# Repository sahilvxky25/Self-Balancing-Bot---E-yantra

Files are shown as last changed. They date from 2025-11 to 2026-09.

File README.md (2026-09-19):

# Self Balncing Bot - E-yantra

## 2025-26

## Project Overview
This repository contains the hardware design assets, control firmware, and task-wise implementation files for the e-Yantra self-balancing bot project by Team IN KrishiBalancer.

The robot is a two-wheeled self-balancing platform with differential drive, IMU-based attitude estimation, encoder feedback, and PID-based control for balance and motion.

## System Details
### Control Approach
- Inner loop: angle stabilization PID for upright balance
- Outer loop: velocity PID for movement regulation
- Yaw control support for turning and heading correction

### Core Hardware/Modules Used
- MPU6050 IMU (tilt and angular-rate sensing)
- Dual DC motors with driver-based PWM control
- Wheel encoders for velocity feedback
- Servo interfaces (used in task-specific implementations)
- Bluetooth serial interface in task variants

### Repository Content Includes
- Arduino firmware files for multiple tasks (`*.ino`)
- Python simulation/control scripts for task solutions (`task*_solution.py`, `Task*.py`)
- Mechanical CAD/export files (`*.stl`, `*.f3d`)
- Reference PDFs for arena/obstacles and rotation matrix

### Participants
- Sahil Patra
- Somya Ranjan Suar
- Aiyush Anand
- H Noah Siddhant

### Team
- IN KrishiBalancer
- From NIT Rourkela

## Links
- https://youtu.be/N_6_f0RvH_E - Task 4B
- https://youtu.be/0fvfJjwpf_w - Task 5B
- https://youtu.be/oQIns9DvQoQ - Task 6
- https://youtu.be/U5AuzeMZjNM - Task 6- Bonus Configuration

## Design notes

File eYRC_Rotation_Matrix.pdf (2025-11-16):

November 13, 2025

## 1 Introduction

2D Rotation Matrix and Vector Rotation

A rotation in two-dimensional space by an angle θ (measured counterclockwise) about the origin can be represented using the rotation matrix:

R(θ) =
cos θ − sin θ
sin θ cos θ

Let the original vector be

v =

x
y

When this vector is rotated by an angle θ, the new vector v

′
is obtained by
multiplying the rotation matrix with the original vector:

v

′ = R(θ)v =

cos θ − sin θ
sin θ cos θ

x
y
=
x cos θ − y sin θ
x sin θ + y cos θ

Hence, the rotated vector v

′ has coordinates

(x

′

, y′
) = (x cos θ − y sin θ, x sin θ + y cos θ).

Transforming Position Error from Global Frame to Robot Frame

Let the position error in the global (world) frame be represented as

eg =

dx

dy
,

and let the robot’s orientation (heading) be given by the angle θ = yaw, measured counterclockwise.
To express this error vector in the robot’s local coordinate frame, we must rotate it by an angle −θ (i.e., the inverse of the robot’s heading). This transformation is given by the rotation matrix:

R(−θ) =
cos θ sin θ
− sin θ cos θ

1

Hence, the error vector in the robot’s frame is:

er = R(−θ)eg =

cos θ sin θ
− sin θ cos θ

dx

dy
=
cos θ dx + sin θ dy

− sin θ dx + cos θ dy

The components of er are therefore:
(
x

′ = cos θ dx + sin θ dy, (lateral error)

y

′ = − sin θ dx + cos θ dy, (forward error)

Thus, the forward position error (along the robot’s local y-axis) is:

position error = cos θ dy − sin θ dx

(*Note- You need to use x and y component of setpoint to calculate dx and dy)

2

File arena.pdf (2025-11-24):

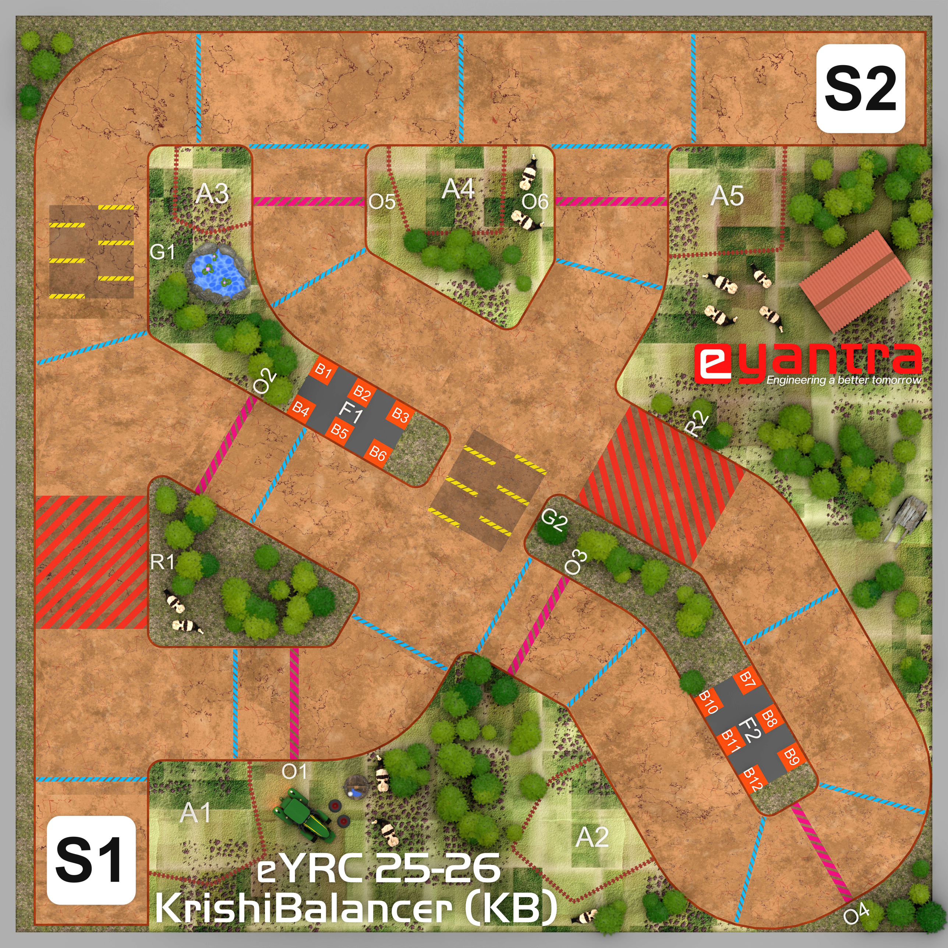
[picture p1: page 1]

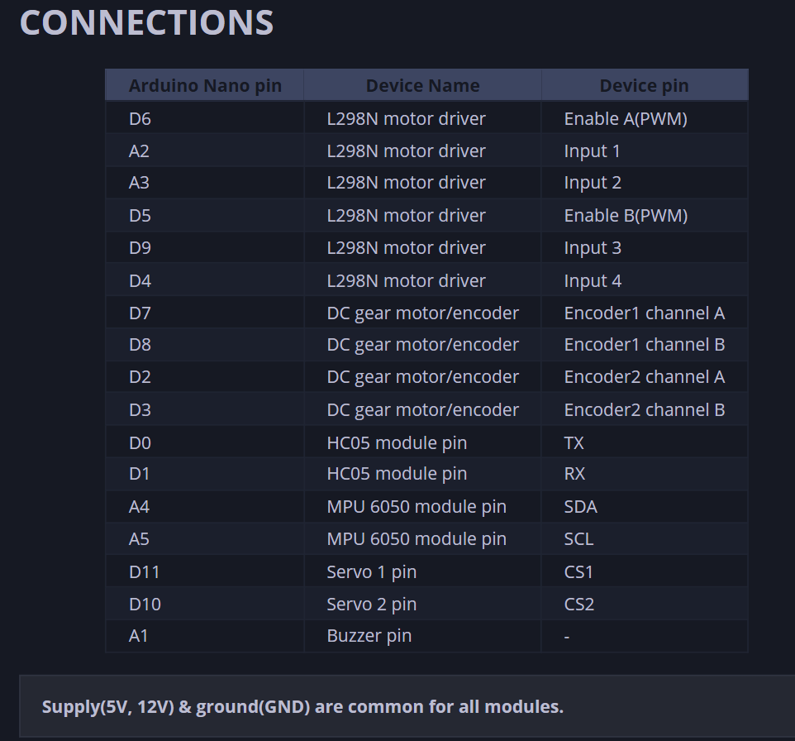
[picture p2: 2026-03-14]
{E6FBB188-6DD0-4D14-BB2B-AFEDF53BD891}.png

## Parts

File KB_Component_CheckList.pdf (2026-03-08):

## eYRC 2024-25 Krishi_Balance (KB) Theme Component Checklist

Sr. No. | Component Name | Image | Qty | Verified by Theme Develop er | Verified by Team | Product Details / DataSheet / Manual
1 | Arduino Nano | | 1 | | | specification (https://robu.in/product/arduino-nano-board-r3-with-ch340-chip-wo-usb-cable-solderedarduino-nano-r3-wo-usb-cable-soldered/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)
| USB-B type Mini cable (Arduino nano cable) | | 1 | | | –
| N20 Motors | | 2 | | | specification (https://robu.in/product/n20-12v-300rpm-micro-metal-gear-motor-with-encoder/)
| N20 Wheels | | 2 | | | specification (https://robu.in/product/3pi-miniq-car-wheel-tyre-42mm-n20-dc-gear-motor-wheel/)
| N20 Clamp, bolts, and nuts | | 2 clamps, 4 bolts, 4 nuts | | | –
| N20 Motor connectors | | 2 | | | –
3 | MPU6050 | | 1 | | | link (https://robu.in/product/mpu-6050-gyro-sensor-2-accelerometer/?gad_source=1)
| Bluetooth Module | | 1 | | | manual (https://components101.com/sites/default/files/component_datasheet/HC-05%20Datasheet.pdf)
| Voltage Checker | | 1 | | | –

2

Sr. No. | Component Name | Image | Qty | Verified by Theme Develop er | Verified by Team | Product Details / DataSheet / Manual
| Jumper caps | | 6 | | | –
| MG90S Servo Motor | | 2 | | | specification (https://robu.in/product/towerpro-mg90s-mini-digital-servo-motor-180-rotation-standard-quality/?gad_source=4)
| Toggle switch | | 1 | | | specification (https://robu.in/product/mini-mts-203-6-pin-dpdt-6a-125vac-toggle-switch-pack-of-5/)
5 | Li-po Battery 3S 1000mAh | | 1 | | | specification (https://robokits.co.in/batteries-chargers/skycell-li-ion-battery/7.4v-li-ion-batteries-6.4-8.4v/lithium-ion-rechargeable-battery-pack-7.4v-2000mah-2c)

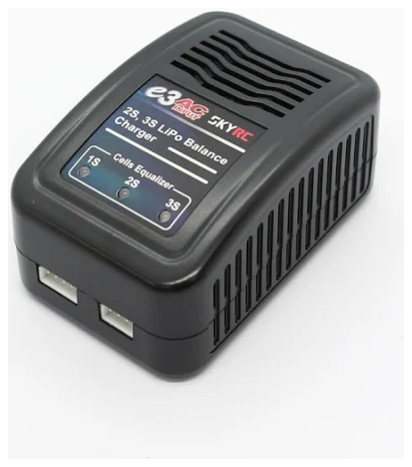
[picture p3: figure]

6 | Battery Adaptor | | 1 | | | –

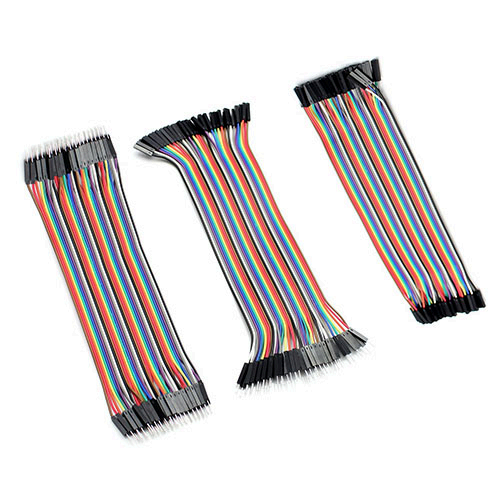
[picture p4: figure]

7 | Jumper Wires (M/M, M/F, F/F) | | 20 each | | | --
8 | Bolts (3mm) and Nuts (3mm) | | 16 Bolts, 8 nuts | | | --
| Spacers 6cm (F/F) | | 6 | | | –
9 | PCB | | 1 | | | --

4

Sr. No. | Component Name | Image | Qty | Verified by Theme Develop er | Verified by Team | Product Details / DataSheet / Manual
| XL4015 Buck converter | | 1
10 | Foam Cubes (5x5x5 cubic cm) | | 7 | | | —

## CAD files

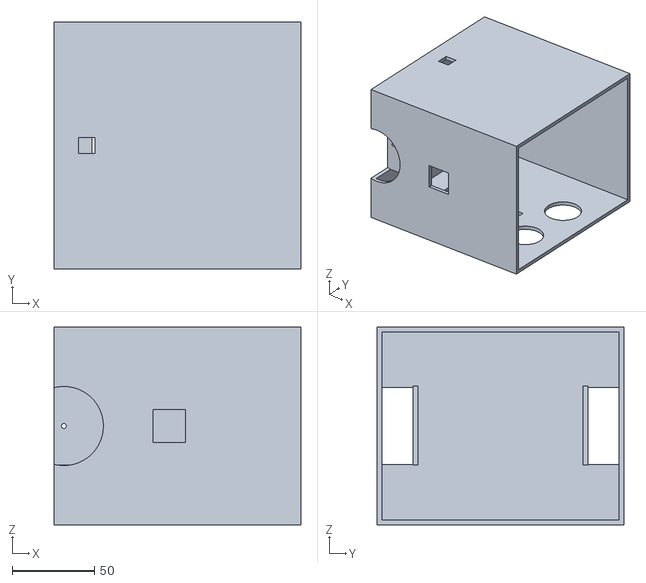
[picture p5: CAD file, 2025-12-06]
MAIN CHASSIS.stl
150.0 x 150.0 x 120.0

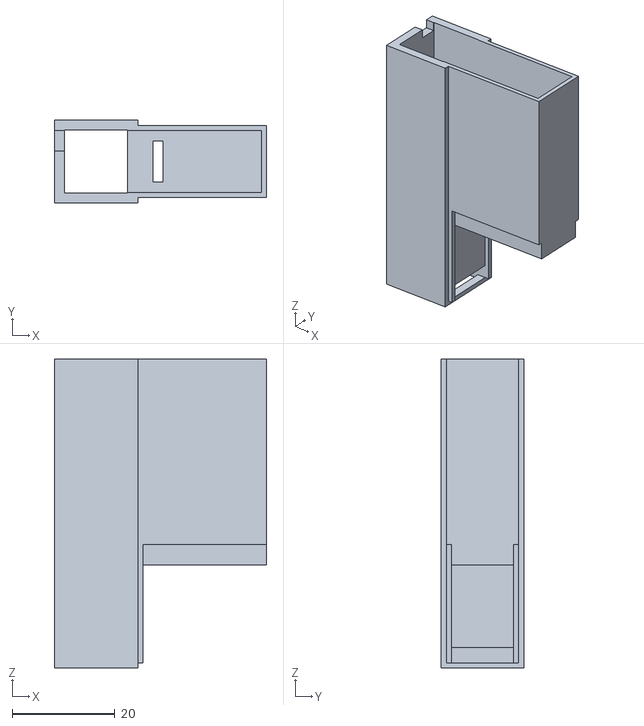
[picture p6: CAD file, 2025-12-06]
main_arm.stl
41.2 x 16.2 x 60.0

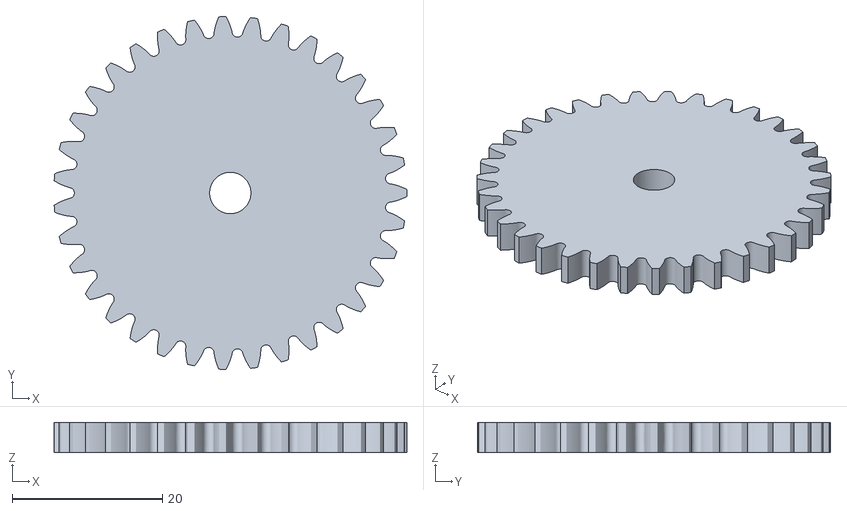
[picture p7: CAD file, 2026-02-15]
Spur Gear (35 teeth).stl
46.9 x 47.0 x 4.00

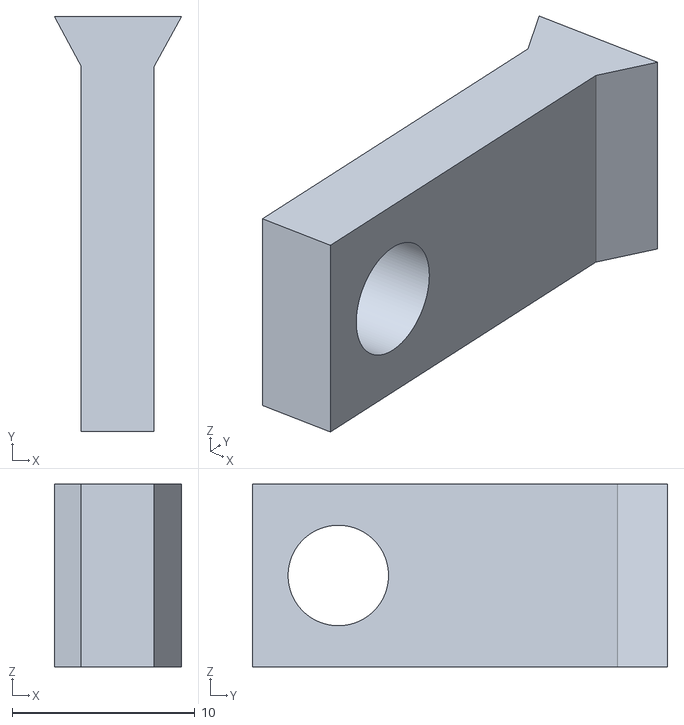
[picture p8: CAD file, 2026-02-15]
Mounter.stl
6.97 x 22.7 x 10.0

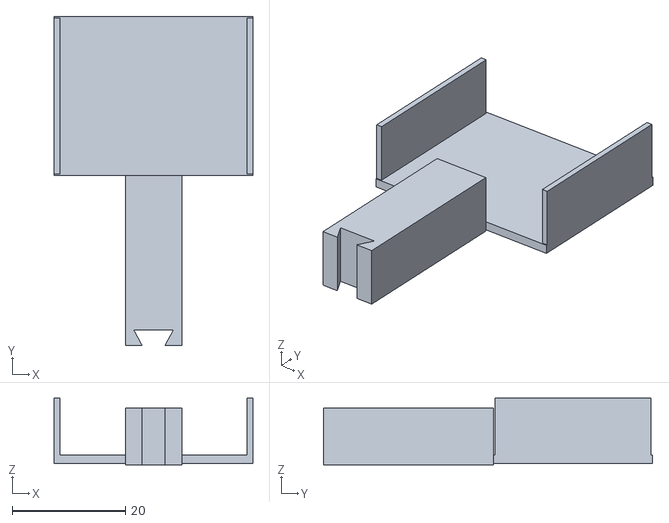
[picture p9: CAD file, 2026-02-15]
servo_rack.stl
35.0 x 58.0 x 11.8

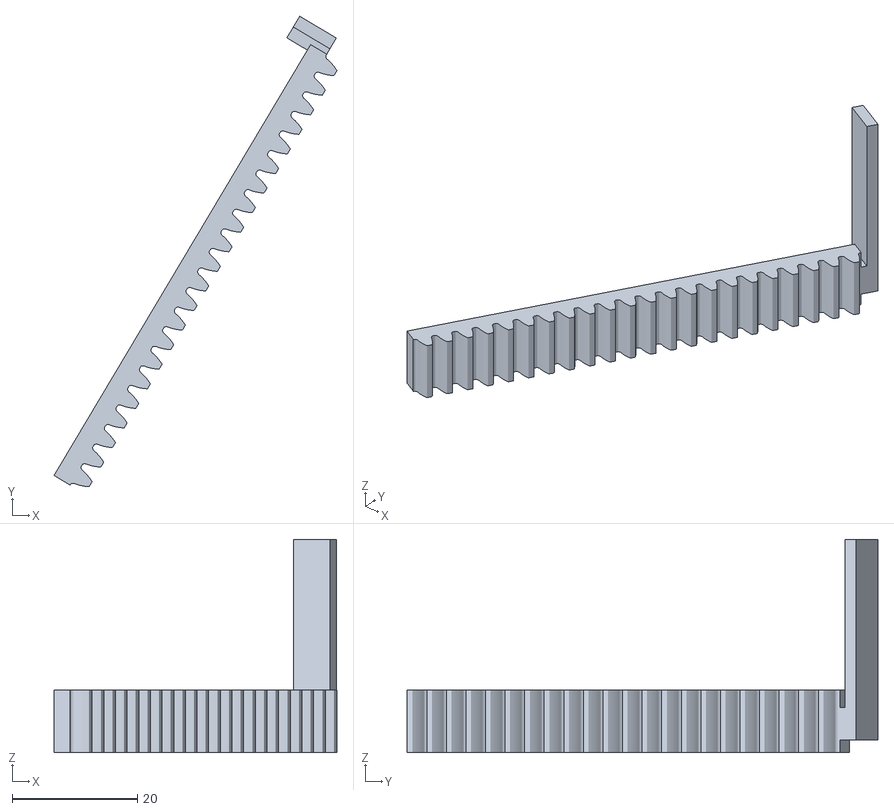
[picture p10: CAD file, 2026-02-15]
Linear Gear.stl
45.1 x 75.1 x 34.0

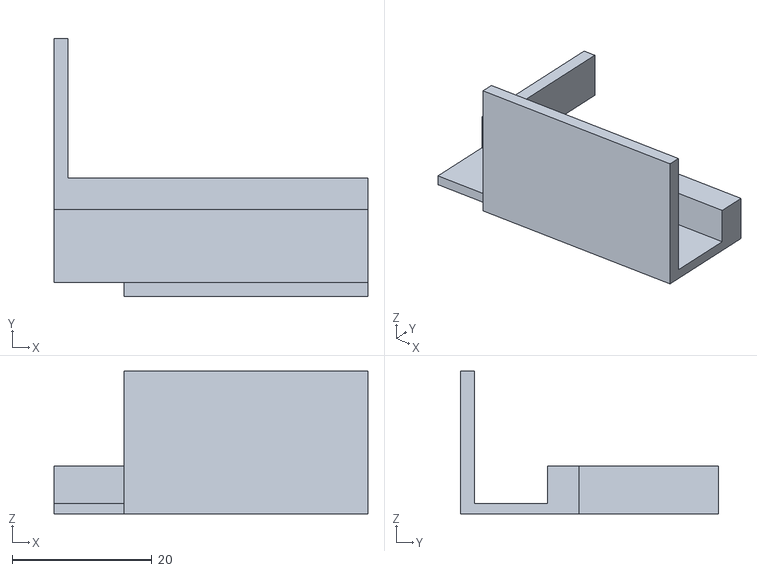
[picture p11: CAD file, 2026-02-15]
Gear_Rack.stl
45.0 x 37.0 x 20.5

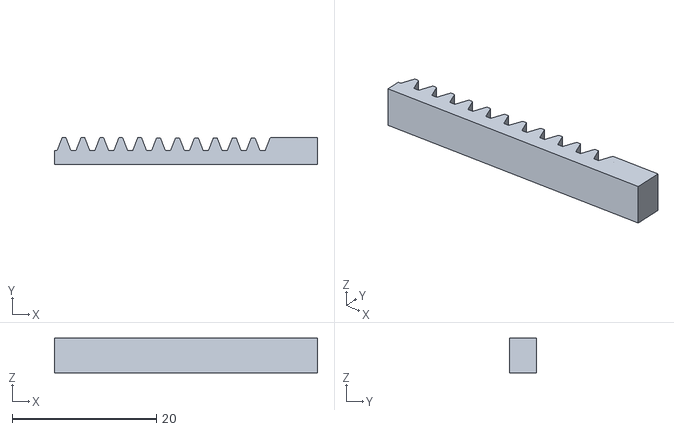
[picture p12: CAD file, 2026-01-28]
real_linear_gear.stl
36.5 x 3.68 x 4.84

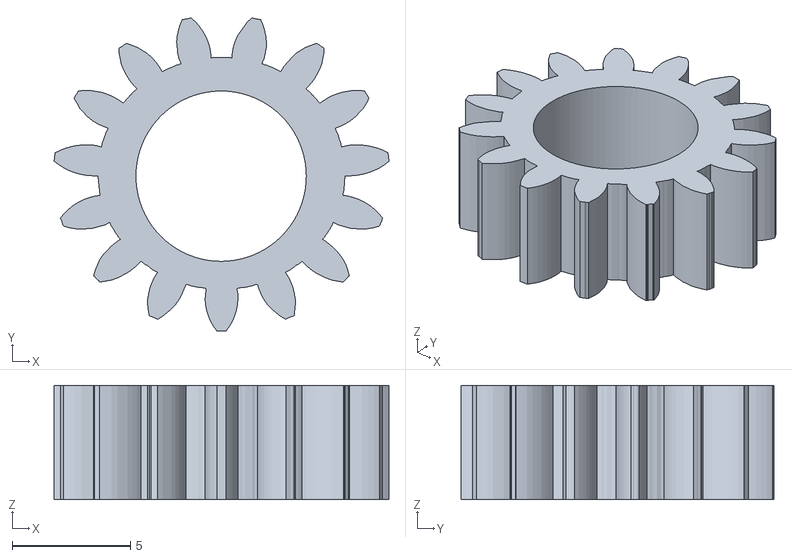
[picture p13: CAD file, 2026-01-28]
real_round_gear.stl
14.2 x 13.2 x 4.84

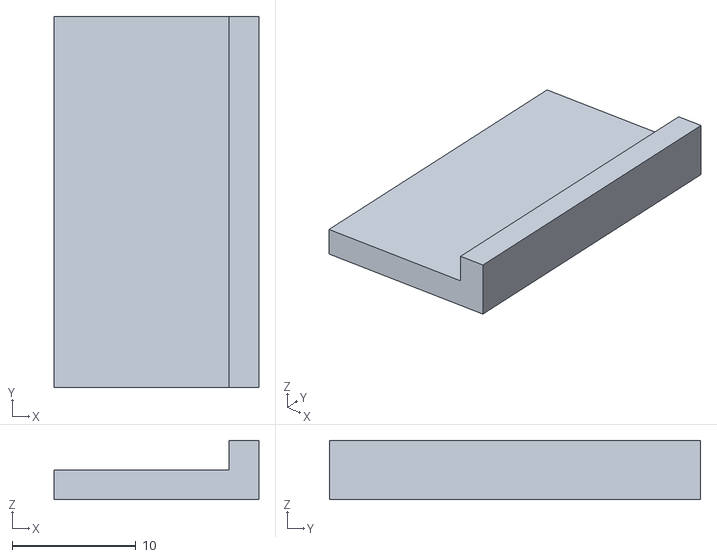
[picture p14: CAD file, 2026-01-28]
real_extra.stl
16.5 x 30.0 x 4.80

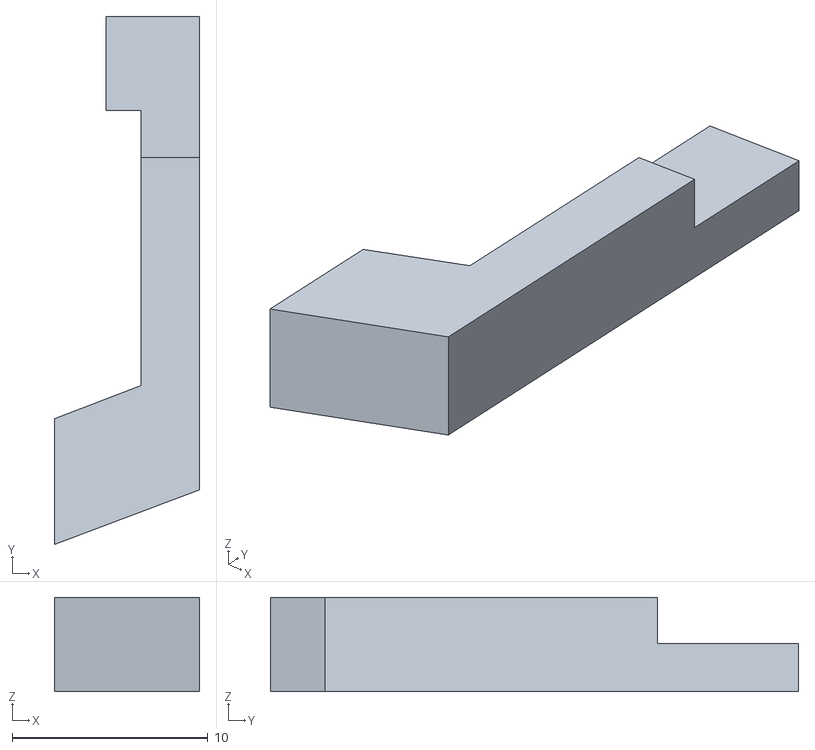
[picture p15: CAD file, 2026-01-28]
real_arm.stl
7.43 x 27.0 x 4.81

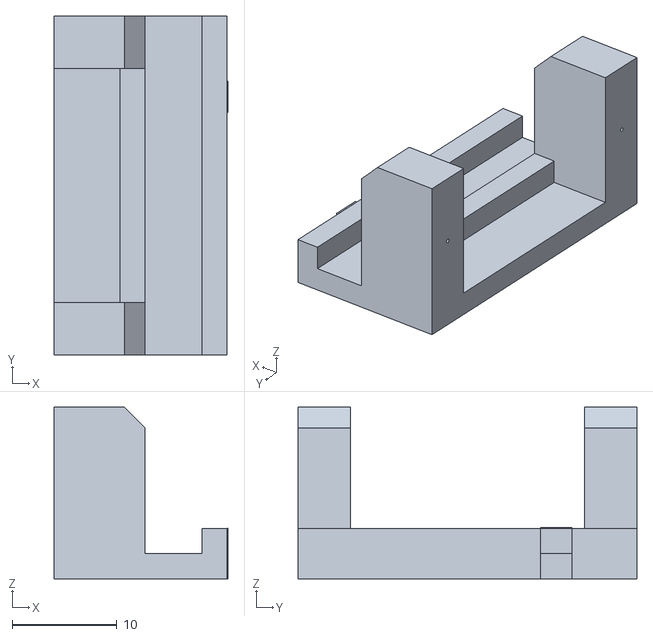
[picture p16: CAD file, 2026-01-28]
real_mount.stl
16.6 x 32.4 x 16.4

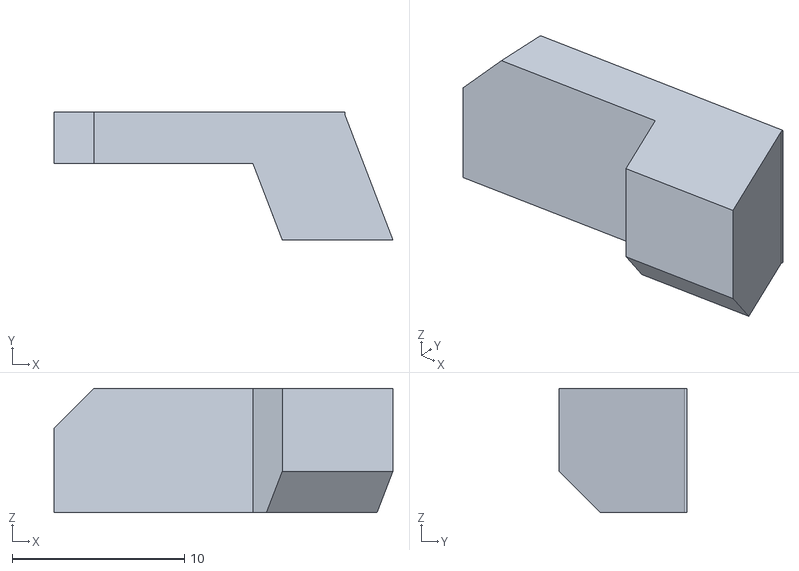
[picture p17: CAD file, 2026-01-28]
gripper_fixed.stl
19.7 x 7.43 x 7.21

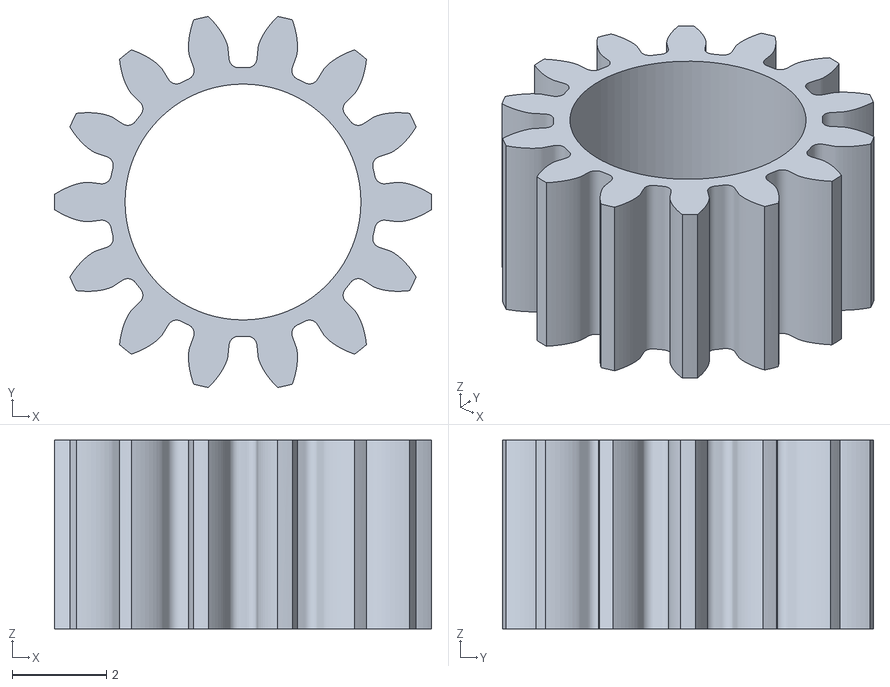
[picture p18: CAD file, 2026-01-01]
GEAR.stl
8.00 x 7.86 x 4.00

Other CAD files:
MANIPULATOR_NEW.stl
GRIP.stl
LONG GRIP.stl
gripper_1.stl
CAP.stl
Gravel_Obstacle.stl
Obstacle_1.stl
SHELF.stl
Spur Gear (14 teeth).stl
chassis_V1.f3d
gear_linear.stl
gripper_2.stl
hinge holder.stl
hinge.stl
manipulator_V1.f3d
ramp_obstacle.stl
servo1_rack.stl

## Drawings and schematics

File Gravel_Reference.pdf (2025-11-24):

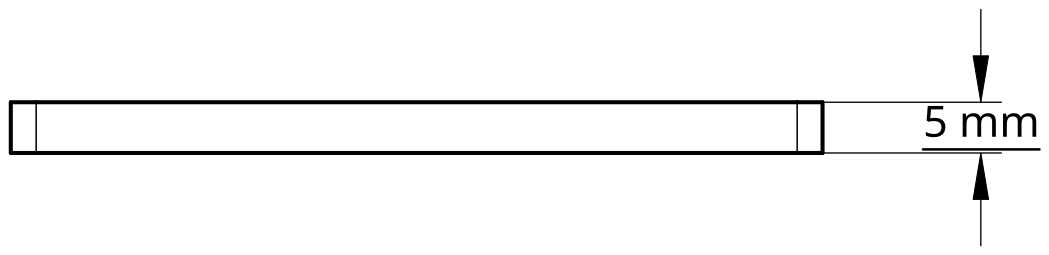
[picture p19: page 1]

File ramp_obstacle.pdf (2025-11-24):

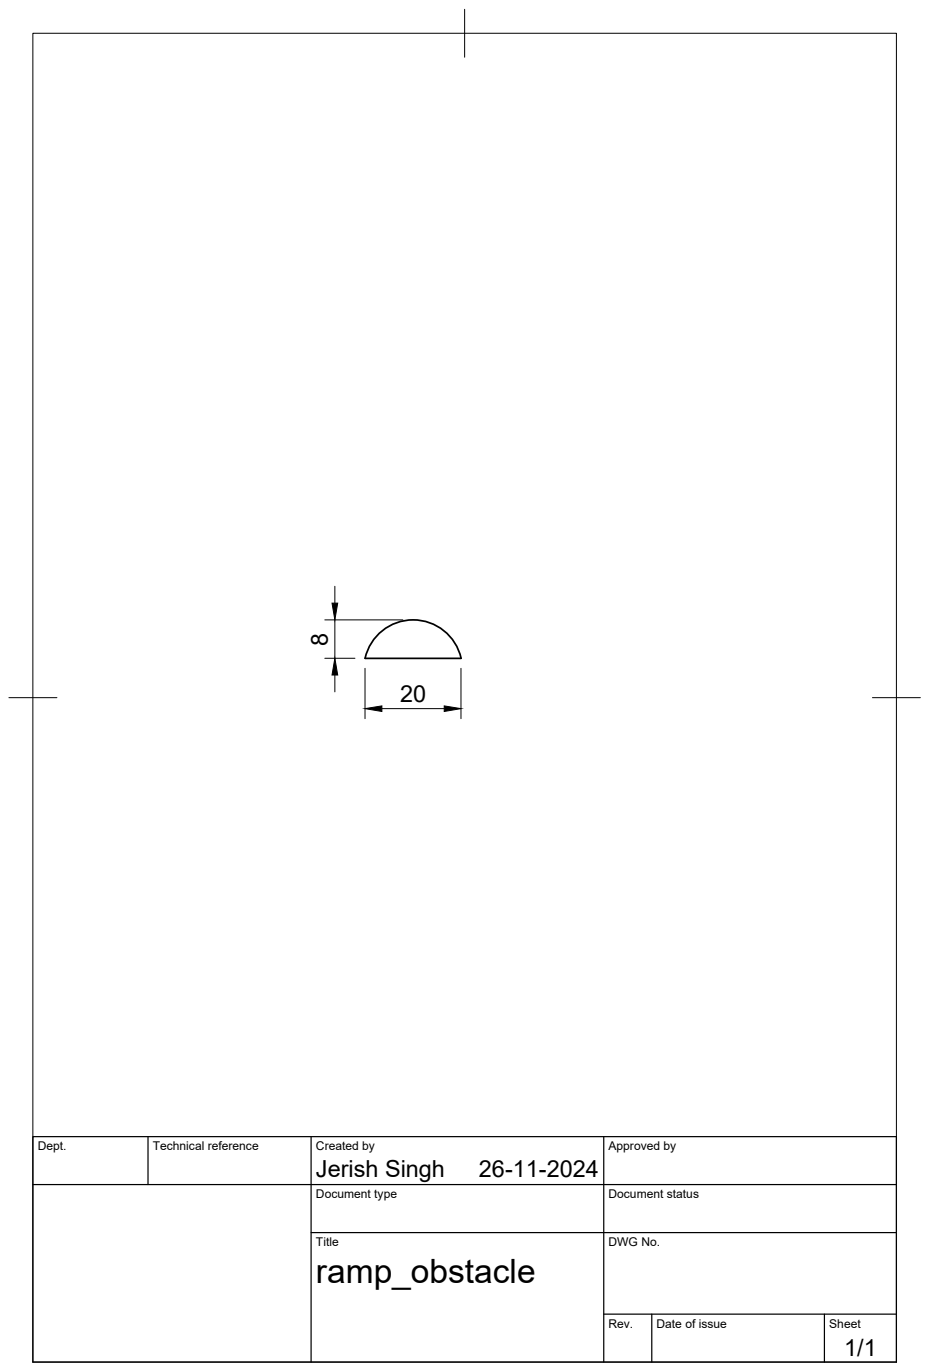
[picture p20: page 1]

Dept. | Technical reference | Created by Jerish Singh 26-11-2024 | Approved by

Document type | Document status

Title ramp_obstacle | DWG No.

Rev. | Date of issue | Sheet 1/1

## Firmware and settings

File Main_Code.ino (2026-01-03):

//#define PRINT_DEBUG_BUILD   // Enable Serial debug prints when required

/* ==============================================================
                          LIBRARIES
   ============================================================== */

/*
 Library: PID_v1
 Purpose : Implements discrete PID control algorithm
*/
#include <PID_v1.h>

/*
 Library: Servo
 Purpose : Controls standard RC servo motors
*/
#include <Servo.h>

/*
 Library: I2Cdev
 Purpose : Low-level I2C communication abstraction
*/
#include "I2Cdev.h"

/*
 Library: MPU6050 DMP Driver
 Purpose : Provides access to MPU6050 sensor and DMP features
*/
#include "MPU6050_6Axis_MotionApps20.h"

/*
 Conditional inclusion of Arduino Wire library
*/
#if I2CDEV_IMPLEMENTATION == I2CDEV_ARDUINO_WIRE
  #include "Wire.h"
#endif

/* ==============================================================
                          MPU6050 VARIABLES
   ============================================================== */

/*
 Variable Name: mpu
 Description  : MPU6050 object handling IMU sensor and DMP
 Range        : Hardware interface object
*/
MPU6050 mpu;

/*
 Variable Name: dmpReady
 Description  : Indicates whether DMP initialization was successful
 Range        : true / false
*/
bool dmpReady = false;

/*
 Variable Name: devStatus
 Description  : Status code returned by DMP initialization
                0 = success, non-zero = error
 Range        : 0–255
*/
uint8_t devStatus;

/*
 Variable Name: packetSize
 Description  : Size (in bytes) of one DMP FIFO packet
 Range        : Typically 42 or 48 bytes
*/
uint16_t packetSize;

/*
 Variable Name: fifoBuffer
 Description  : Buffer storing raw DMP FIFO data
 Range        : Byte array [0–63]
*/
uint8_t fifoBuffer[64];

/*
 Variable Name: q
 Description  : Quaternion representing orientation
*/
Quaternion q;

/*
 Variable Name: gravity
 Description  : Gravity vector extracted from quaternion
*/
VectorFloat gravity;

/*
 Variable Name: gy
 Description  : Raw gyroscope readings (X, Y, Z axes)
*/
VectorInt16 gy;

/*
 Variable Name: ypr
 Description  : Yaw, Pitch, Roll angles from DMP
 Range        : Radians
 Index        : [0] Yaw, [1] Pitch, [2] Roll
*/
float ypr[3];

/* ==============================================================
                          PID PARAMETERS
   ============================================================== */

/*
 Variable Name: PID_MIN_LIMIT / PID_MAX_LIMIT
 Description  : Output saturation limits for motor PWM
 Range        : -255 to +255
*/
#define PID_MIN_LIMIT -255
#define PID_MAX_LIMIT  255

/*
 Variable Name: PID_SAMPLE_TIME
 Description  : PID computation interval in milliseconds
 Range        : 5–20 ms recommended
*/
#define PID_SAMPLE_TIME 10

/*
 Variable Name: SETPOINT_PITCH_ANGLE_OFFSET
 Description  : Static balance angle offset due to COM shift
 Range        : Approximately -15° to +15°
*/
#define SETPOINT_PITCH_ANGLE_OFFSET -8

/*
 Variable Name: MIN_ABSOLUTE_SPEED
 Description  : Minimum PWM applied to overcome motor dead zone
 Range        : 0–50
*/
#define MIN_ABSOLUTE_SPEED 15

/*
 Variable Name: setpointPitchAngle
 Description  : Desired pitch angle for self-balancing
 Range        : Degrees
*/
double setpointPitchAngle = SETPOINT_PITCH_ANGLE_OFFSET;

/*
 Variable Name: pitchGyroAngle
 Description  : Measured pitch angle from MPU DMP
 Range        : Degrees
*/
double pitchGyroAngle = 0;

/*
 Variable Name: pitchPIDOutput
 Description  : Output of pitch PID controller
 Range        : -255 to +255
*/
double pitchPIDOutput = 0;

/*
 Variable Name: setpointYawRate
 Description  : Desired yaw rate (no rotation by default)
 Range        : Degrees/second
*/
double setpointYawRate = 0;

/*
 Variable Name: yawGyroRate
 Description  : Measured yaw angular velocity
 Range        : Raw gyro units
*/
double yawGyroRate = 0;

/*
 Variable Name: yawPIDOutput
 Description  : Yaw correction term added to motors
 Range        : -60 to +60
*/
double yawPIDOutput = 0;

/* ==============================================================
                          PID OBJECTS
   ============================================================== */

/*
 Pitch PID Controller
 Purpose : Maintains upright balance (inner loop)
*/
PID pitchPID(&pitchGyroAngle, &pitchPIDOutput, &setpointPitchAngle,
             28.0, 0.8, 1.2, DIRECT);

/*
 Yaw PID Controller
 Purpose : Provides heading stabilization
*/
PID yawPID(&yawGyroRate, &yawPIDOutput, &setpointYawRate,
           1.0, 0.3, 0.0, DIRECT);

/* ==============================================================
                          MOTOR PINS
   ============================================================== */

/*
 Left Motor (L298N Channel A)
*/
#define EN1 6
#define IN1 A2
#define IN2 A3

/*
 Right Motor (L298N Channel B)
*/
#define EN2 5
#define IN3 9
#define IN4 4

/* ==============================================================
                          ENCODERS
   ============================================================== */

/*
 Variable Name: ENC_L_A / ENC_L_B
 Description  : Left motor encoder channels
*/
#define ENC_L_A 7
#define ENC_L_B 8

/*
 Variable Name: ENC_R_A / ENC_R_B
 Description  : Right motor encoder channels
*/
#define ENC_R_A 2
#define ENC_R_B 3

/*
 Variable Name: encoderLeft / encoderRight
 Description  : Encoder pulse counters
 Range        : 0 to large integer (depends on runtime)
*/
volatile long encoderLeft = 0;
volatile long encoderRight = 0;

/* ==============================================================
                          OTHER DEVICES
   ============================================================== */

/*
 Variable Name: BUZZER_PIN
 Description  : Buzzer control pin
*/
#define BUZZER_PIN A1

/*
 Variable Name: SERVO1_PIN / SERVO2_PIN
 Description  : Servo control pins
*/
#define SERVO1_PIN 11
#define SERVO2_PIN 10

Servo servo1;
Servo servo2;

/* ==============================================================
 Function Name : encoderLeftISR
 Input         : None
 Output        : None
 Logic         : Increments left encoder count on rising edge
 Example Call  : Triggered by hardware interrupt
 ============================================================== */
void encoderLeftISR() {
  encoderLeft++;
}

/* ==============================================================
 Function Name : encoderRightISR
 Input         : None
 Output        : None
 Logic         : Increments right encoder count on rising edge
 Example Call  : Triggered by hardware interrupt
 ============================================================== */
void encoderRightISR() {
  encoderRight++;
}

/* ==============================================================
 Function Name : rotateMotor
 Input         :
   speedL → Left motor command (-255 to +255)
   speedR → Right motor command (-255 to +255)
 Output        : None
 Logic         :
   • Determines motor direction
   • Adds dead-zone compensation
   • Applies PWM to L298N driver
 Example Call  : rotateMotor(120, -80);
 ============================================================== */
void rotateMotor(int speedL, int speedR) {

  // Left Motor Direction
  if (speedL < 0) {
    digitalWrite(IN1, LOW);
    digitalWrite(IN2, HIGH);
  } else {
    digitalWrite(IN1, HIGH);
    digitalWrite(IN2, LOW);
  }

  // Right Motor Direction (inverted wiring)
  if (speedR < 0) {
    digitalWrite(IN3, HIGH);
    digitalWrite(IN4, LOW);
  } else {
    digitalWrite(IN3, LOW);
    digitalWrite(IN4, HIGH);
  }

  speedL = constrain(abs(speedL) + MIN_ABSOLUTE_SPEED, 0, 255);
  speedR = constrain(abs(speedR) + MIN_ABSOLUTE_SPEED, 0, 255);

  analogWrite(EN1, speedL);
  analogWrite(EN2, speedR);
}

/* ==============================================================
 Function Name : setup
 Input         : None
 Output        : None
 Logic         :
   • Initializes I2C, motors, encoders, MPU6050, PID controllers
   • Plays startup buzzer
 Example Call  : Automatically executed at boot
 ============================================================== */
void setup() {

#if I2CDEV_IMPLEMENTATION == I2CDEV_ARDUINO_WIRE
  Wire.begin();
  Wire.setClock(400000);
#endif

#ifdef PRINT_DEBUG_BUILD
  Serial.begin(115200);
#endif

  // Motor pin setup
  pinMode(EN1, OUTPUT);
  pinMode(IN1, OUTPUT);
  pinMode(IN2, OUTPUT);

  pinMode(EN2, OUTPUT);
  pinMode(IN3, OUTPUT);
  pinMode(IN4, OUTPUT);

  // Encoder pin setup
  pinMode(ENC_L_A, INPUT_PULLUP);
  pinMode(ENC_L_B, INPUT_PULLUP);
  pinMode(ENC_R_A, INPUT_PULLUP);
  pinMode(ENC_R_B, INPUT_PULLUP);

  attachInterrupt(digitalPinToInterrupt(ENC_L_A), encoderLeftISR, RISING);
  attachInterrupt(digitalPinToInterrupt(ENC_R_A), encoderRightISR, RISING);

  // Buzzer startup indication
  pinMode(BUZZER_PIN, OUTPUT);
  tone(BUZZER_PIN, 2000, 150);
  delay(200);
  noTone(BUZZER_PIN);

  // Servo initialization
  servo1.attach(SERVO1_PIN);
  servo2.attach(SERVO2_PIN);
  servo1.write(90);
  servo2.write(90);

  // MPU6050 initialization
  mpu.initialize();
  devStatus = mpu.dmpInitialize();

  mpu.setXAccelOffset(-4092);
  mpu.setYAccelOffset(687);
  mpu.setZAccelOffset(1430);
  mpu.setXGyroOffset(132);
  mpu.setYGyroOffset(-3);
  mpu.setZGyroOffset(47);

  if (devStatus == 0) {
    mpu.setDMPEnabled(true);
    packetSize = mpu.dmpGetFIFOPacketSize();
    dmpReady = true;
  }

  // PID configuration
  pitchPID.SetOutputLimits(PID_MIN_LIMIT, PID_MAX_LIMIT);
  pitchPID.SetSampleTime(PID_SAMPLE_TIME);
  pitchPID.SetMode(AUTOMATIC);

  yawPID.SetOutputLimits(-60, 60);
  yawPID.SetSampleTime(PID_SAMPLE_TIME);
  yawPID.SetMode(AUTOMATIC);

  rotateMotor(0, 0);
}

/* ==============================================================
 Function Name : loop
 Input         : None
 Output        : None
 Logic         :
   • Reads IMU data
   • Computes PID outputs
   • Drives motors for balance
 Example Call  : Runs continuously
 ============================================================== */
void loop() {

  if (!dmpReady) return;

  if (mpu.dmpGetCurrentFIFOPacket(fifoBuffer)) {

    mpu.dmpGetQuaternion(&q, fifoBuffer);
    mpu.dmpGetGravity(&gravity, &q);
    mpu.dmpGetYawPitchRoll(ypr, &q, &gravity);
    mpu.dmpGetGyro(&gy, fifoBuffer);

    pitchGyroAngle = ypr[1] * 180.0 / M_PI;
    yawGyroRate = gy.z;

    pitchPID.Compute();
    yawPID.Compute();

    int leftMotor  = pitchPIDOutput + yawPIDOutput;
    int rightMotor = pitchPIDOutput - yawPIDOutput;

    rotateMotor(leftMotor, rightMotor);

#ifdef PRINT_DEBUG_BUILD
    Serial.print("Pitch: ");
    Serial.print(pitchGyroAngle);
    Serial.print(" | EncL: ");
    Serial.print(encoderLeft);
    Serial.print(" | EncR: ");
    Serial.println(encoderRight);
#endif
  }
}

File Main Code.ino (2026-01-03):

//#define PRINT_DEBUG_BUILD   // Uncomment to enable Serial debug prints

#include <PID_v1.h>
#include "I2Cdev.h"
#include "MPU6050_6Axis_MotionApps20.h"

/* ========================= I2C CONFIG =========================
   Uses Arduino Wire implementation for I2C communication
*/
#if I2CDEV_IMPLEMENTATION == I2CDEV_ARDUINO_WIRE
  #include "Wire.h"
#endif

/* ==============================================================
                          MPU6050 SECTION
   ============================================================== */

/*
 Variable Name: mpu
 Description  : MPU6050 IMU object handling accelerometer + gyroscope + DMP
 Range        : N/A (hardware interface)
*/
MPU6050 mpu;

/*
 Variable Name: INTERRUPT_PIN
 Description  : Arduino pin connected to MPU6050 INT pin
 Range        : Digital pin number
*/
#define INTERRUPT_PIN 2   // D2 as per PCB design

/*
 Variable Name: dmpReady
 Description  : Flag indicating whether DMP initialization succeeded
 Range        : true / false
*/
bool dmpReady = false;

/*
 Variable Name: mpuIntStatus
 Description  : Holds MPU interrupt status register value
 Range        : 0–255
*/
uint8_t mpuIntStatus;

/*
 Variable Name: devStatus
 Description  : Status returned by DMP initialization
                0 → success, non-zero → failure
 Range        : 0–255
*/
uint8_t devStatus;

/*
 Variable Name: packetSize
 Description  : Size (in bytes) of one DMP FIFO packet
 Range        : typically 42 or 48 bytes
*/
uint16_t packetSize;

/*
 Variable Name: fifoBuffer
 Description  : Buffer used to store FIFO data from MPU6050
 Range        : byte array
*/
uint8_t fifoBuffer[64];

/*
 Variable Name: q
 Description  : Quaternion representing orientation
*/
Quaternion q;

/*
 Variable Name: gravity
 Description  : Gravity vector extracted from quaternion
*/
VectorFloat gravity;

/*
 Variable Name: gy
 Description  : Raw gyroscope readings (X, Y, Z)
*/
VectorInt16 gy;

/*
 Variable Name: ypr
 Description  : Yaw, Pitch, Roll angles in radians
 Index        : [0]=Yaw, [1]=Pitch, [2]=Roll
*/
float ypr[3];

/*
 Variable Name: mpuInterrupt
 Description  : Set true when MPU interrupt occurs
*/
volatile bool mpuInterrupt = false;

/* ==============================================================
 Function Name: dmpDataReady
 Input        : None
 Output       : None
 Logic        : Interrupt Service Routine (ISR) that sets a flag
                when MPU6050 DMP data is ready
 Example Call : Automatically triggered by hardware interrupt
 ============================================================== */
void dmpDataReady() {
  mpuInterrupt = true;
}

/* ==============================================================
                          PID PARAMETERS
   ============================================================== */

/*
 Variable Name: PID_MIN_LIMIT / PID_MAX_LIMIT
 Description  : Saturation limits for motor PWM output
 Range        : -255 to +255
*/
#define PID_MIN_LIMIT -255
#define PID_MAX_LIMIT  255

/*
 Variable Name: PID_SAMPLE_TIME
 Description  : PID computation interval in milliseconds
 Range        : Typically 5–20 ms
*/
#define PID_SAMPLE_TIME 10

/*
 Variable Name: SETPOINT_PITCH_ANGLE_OFFSET
 Description  : Static mechanical offset for balance angle (degrees)
 Range        : Depends on COM shift, usually -15° to +15°
*/
#define SETPOINT_PITCH_ANGLE_OFFSET -8

/*
 Variable Name: MIN_ABSOLUTE_SPEED
 Description  : Minimum PWM applied to overcome motor dead zone
 Range        : 0–50
*/
#define MIN_ABSOLUTE_SPEED 15

/*
 Variable Name: setpointPitchAngle
 Description  : Desired pitch angle for balancing (degrees)
*/
double setpointPitchAngle = SETPOINT_PITCH_ANGLE_OFFSET;

/*
 Variable Name: pitchGyroAngle
 Description  : Measured pitch angle from DMP (degrees)
*/
double pitchGyroAngle = 0;

/*
 Variable Name: pitchPIDOutput
 Description  : Output of pitch PID controller
 Range        : -255 to +255
*/
double pitchPIDOutput = 0;

/*
 տարինYaw variables handle yaw stabilization
*/
double setpointYawRate = 0;   // Desired yaw rate (deg/s)
double yawGyroRate = 0;       // Measured yaw rate
double yawPIDOutput = 0;      // Yaw correction output

/* ========================= PID GAINS ========================= */

/*
 Pitch PID controls balance (inner loop)
*/
#define PID_PITCH_KP 28
#define PID_PITCH_KI 0.8
#define PID_PITCH_KD 1.2

/*
 Yaw PID provides directional correction
*/
#define PID_YAW_KP 1
#define PID_YAW_KI 0.3
#define PID_YAW_KD 0

/*
 Pitch PID Object
 Input  : pitchGyroAngle
 Output : pitchPIDOutput
 Setpoint: setpointPitchAngle
*/
PID pitchPID(&pitchGyroAngle, &pitchPIDOutput, &setpointPitchAngle,
             PID_PITCH_KP, PID_PITCH_KI, PID_PITCH_KD, DIRECT);

/*
 Yaw PID Object
*/
PID yawPID(&yawGyroRate, &yawPIDOutput, &setpointYawRate,
           PID_YAW_KP, PID_YAW_KI, PID_YAW_KD, DIRECT);

/* ==============================================================
                      MOTOR DRIVER CONFIG
   ============================================================== */

/*
 Motor A (Left Motor)
*/
int enableMotor1 = 6;     // PWM pin
int motor1Pin1  = A2;    // Direction pin
int motor1Pin2  = A3;    // Direction pin

/*
 Motor B (Right Motor)
*/
int enableMotor2 = 5;    // PWM pin
int motor2Pin1  = 9;     // Direction pin
int motor2Pin2  = 4;     // Direction pin

/* ==============================================================
 Function Name: setupMotors
 Input        : None
 Output       : None
 Logic        : Initializes motor control pins and stops motors
 Example Call : setupMotors();
 ============================================================== */
void setupMotors() {
  pinMode(enableMotor1, OUTPUT);
  pinMode(motor1Pin1, OUTPUT);
  pinMode(motor1Pin2, OUTPUT);

  pinMode(enableMotor2, OUTPUT);
  pinMode(motor2Pin1, OUTPUT);
  pinMode(motor2Pin2, OUTPUT);

  rotateMotor(0, 0);
}

/* ==============================================================
 Function Name: setupPID
 Input        : None
 Output       : None
 Logic        : Configures PID limits, sampling time, and mode
 Example Call : setupPID();
 ============================================================== */
void setupPID() {
  pitchPID.SetOutputLimits(PID_MIN_LIMIT, PID_MAX_LIMIT);
  pitchPID.SetSampleTime(PID_SAMPLE_TIME);
  pitchPID.SetMode(AUTOMATIC);

  yawPID.SetOutputLimits(-60, 60);
  yawPID.SetSampleTime(PID_SAMPLE_TIME);
  yawPID.SetMode(AUTOMATIC);
}

/* ==============================================================
 Function Name: setupMPU
 Input        : None
 Output       : None
 Logic        : Initializes MPU6050, loads DMP, applies calibration
 Example Call : setupMPU();
 ============================================================== */
void setupMPU() {
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

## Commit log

2025-12-06 3d Model
    [CAP.stl, MAIN CHASSIS.stl, SHELF.stl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]
2025-12-08 Grip Redesigned
    [LONG GRIP.stl]
2026-01-01 MPU Calibration
2026-01-01 New Manipulator Design
    [GEAR.stl, GRIP.stl, MANIPULATOR_NEW.stl]
2026-02-15 Last Manipulator Design
    [Gear_Rack.stl, Linear Gear.stl, Mounter.stl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]
